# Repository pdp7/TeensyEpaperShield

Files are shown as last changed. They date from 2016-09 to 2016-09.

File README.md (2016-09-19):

# TeensyEpaperShield
Teensy shield designed by [Jarek Lupinski](https://hackaday.io/Jarek) to connect e-paper display from [Pervasive Displays](http://www.pervasivedisplays.com/products#iTC):
 > The Simplest Way To Start Playing With A Fascinating New Low-Power Screen!

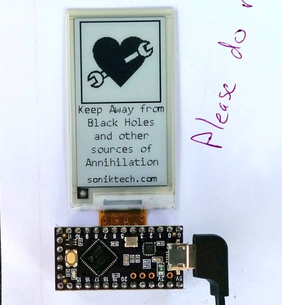
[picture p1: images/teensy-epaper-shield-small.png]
photo of assembled board (https://oshpark.com/shared_projects/3KynIVn6)


## OSH Park Shared Project
* [Teensy e-Paper shield](https://oshpark.com/shared_projects/3KynIVn6)

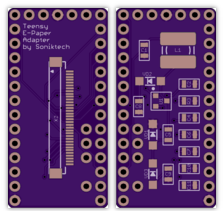
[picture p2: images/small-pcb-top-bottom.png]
PCB preview (https://oshpark.com/shared_projects/3KynIVn6)


## Blog posts
* [Teensy E-Paper shield](https://blog.oshpark.com/2016/08/27/teensy-e-paper-shield/)
* [Teensy E-Paper shield update](https://blog.oshpark.com/2016/09/07/teensy-e-paper-shield-update/)

## Hackaday.io project
* [Teensy E-Paper Adapter Board](https://hackaday.io/project/13327-teensy-e-paper-adapter-board)

## Design files
* [EpaperTeensyBoard.sch](https://cdn.hackaday.io/files/13327570182368/EpaperTeensyBoard.sch)
* [EpaperTeensyBoard.brd](https://cdn.hackaday.io/files/13327570182368/EpaperTeensyBoard.brd)

## Images
* [images dir](/images)

## Video
* [YouTube: Teensy E-Paper Shield](https://www.youtube.com/watch?v=xAe1GGP35UQ)

## Bill of Materials
* [Teensy 3.x](https://oshpark.com/teensy) or [Teensy LC](http://store.oshpark.com/products/teensy-lc)
* [Pervasive Displays 2.15" e-paper with ITC (E2215CS062)](http://www.digikey.com/product-detail/en/pervasive-displays/E2215CS062/E2215CS062-ND/5975949)
* [Hirose Electric Co Ltd FH34SRJ-34S-0.5SH FPC connector]( https://www.digikey.com/short/3hv1q0 )
* [Parts list exported from EAGLE](https://cdn.hackaday.io/files/13327570182368/EpaperTeensyBoardPartlist.txt)
* [Digi-Key shopping cart #1](http://www.digikey.com/short/3mhnrd)
* [Digi-Key shopping cart #2](http://www.digikey.com/short/3m9wq3)

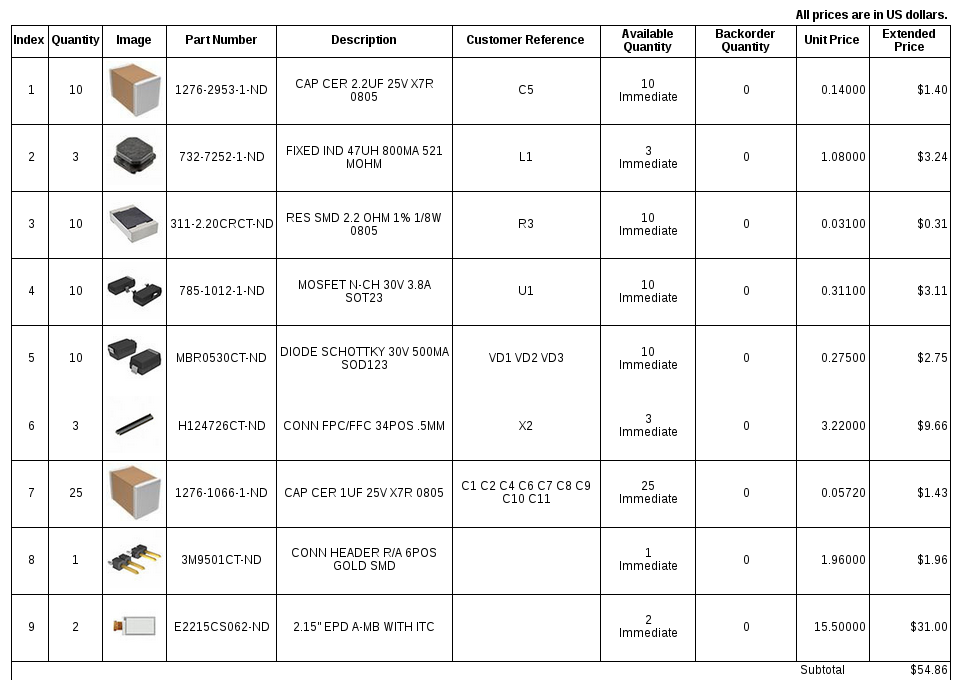
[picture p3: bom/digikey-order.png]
Digi-Key order


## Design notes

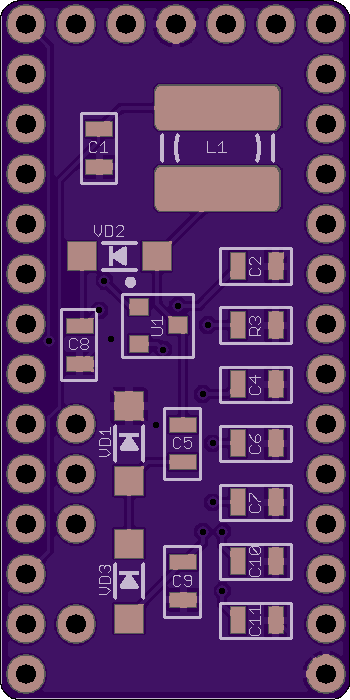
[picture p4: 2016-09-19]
images/pcb-big-bottom.png

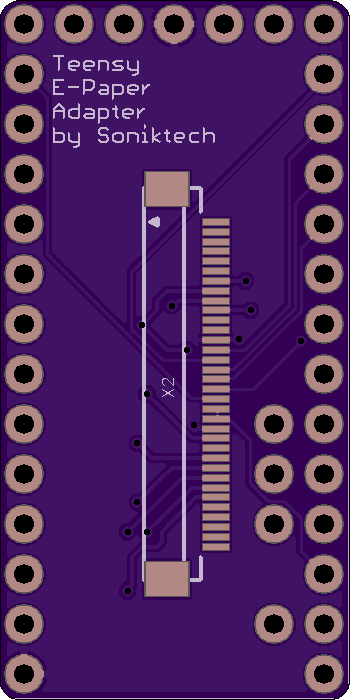
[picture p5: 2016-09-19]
images/pcb-big-top.png

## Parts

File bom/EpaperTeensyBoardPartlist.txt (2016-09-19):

Partlist

Exported from EpaperTeensyBoard.sch at 9/10/2016 6:15 PM

EAGLE Version 7.5.0 Copyright (c) 1988-2015 CadSoft

Assembly variant: 

Part     Value                 Device                 Package            Library                   Sheet

C1       1uF                   CAPACITOR_NP_0805      C0805              MF_Passives               1
C2       1uF                   CAPACITOR_NP_0805      C0805              MF_Passives               1
C4       1uF                   CAPACITOR_NP_0805      C0805              MF_Passives               1
C5       1uF                   CAPACITOR_NP_0805      C0805              MF_Passives               1
C6       1uF                   CAPACITOR_NP_0805      C0805              MF_Passives               1
C7       1uF                   CAPACITOR_NP_0805      C0805              MF_Passives               1
C8       1uF                   CAPACITOR_NP_0805      C0805              MF_Passives               1
C9       1uF                   CAPACITOR_NP_0805      C0805              MF_Passives               1
C10      1uF                   CAPACITOR_NP_0805      C0805              MF_Passives               1
C11      1uF                   CAPACITOR_NP_0805      C0805              MF_Passives               1
J1       TEENSY-3.1NOSILK      TEENSY-3.1NOSILK       TEENSY-3.1_NOSILK  SparkFun-Boards           1
L1       74404052470           L-USWE-TPC             POWER-CHOKE_WE-TPC rcl                       1
R3       2.2?/1%               RESISTOR_0805          R0805              MF_Passives               1
U1       AO3418                N-CHANNEL_FET_SOT-23-3 SOT-23-3           MF_Discrete_Semiconductor 1
VD1      MBR0530               DIODE-SCHOTTKY-SOD123  SOD123             diode                     1
VD2      MBR0530               DIODE-SCHOTTKY-SOD123  SOD123             diode                     1
VD3      MBR0530               DIODE-SCHOTTKY-SOD123  SOD123             diode                     1
X2       FH34SRJ-34S-0.5SH(99) FH12-34S-0.5SH         FH12-34S-0.5SH     con-hirose                1

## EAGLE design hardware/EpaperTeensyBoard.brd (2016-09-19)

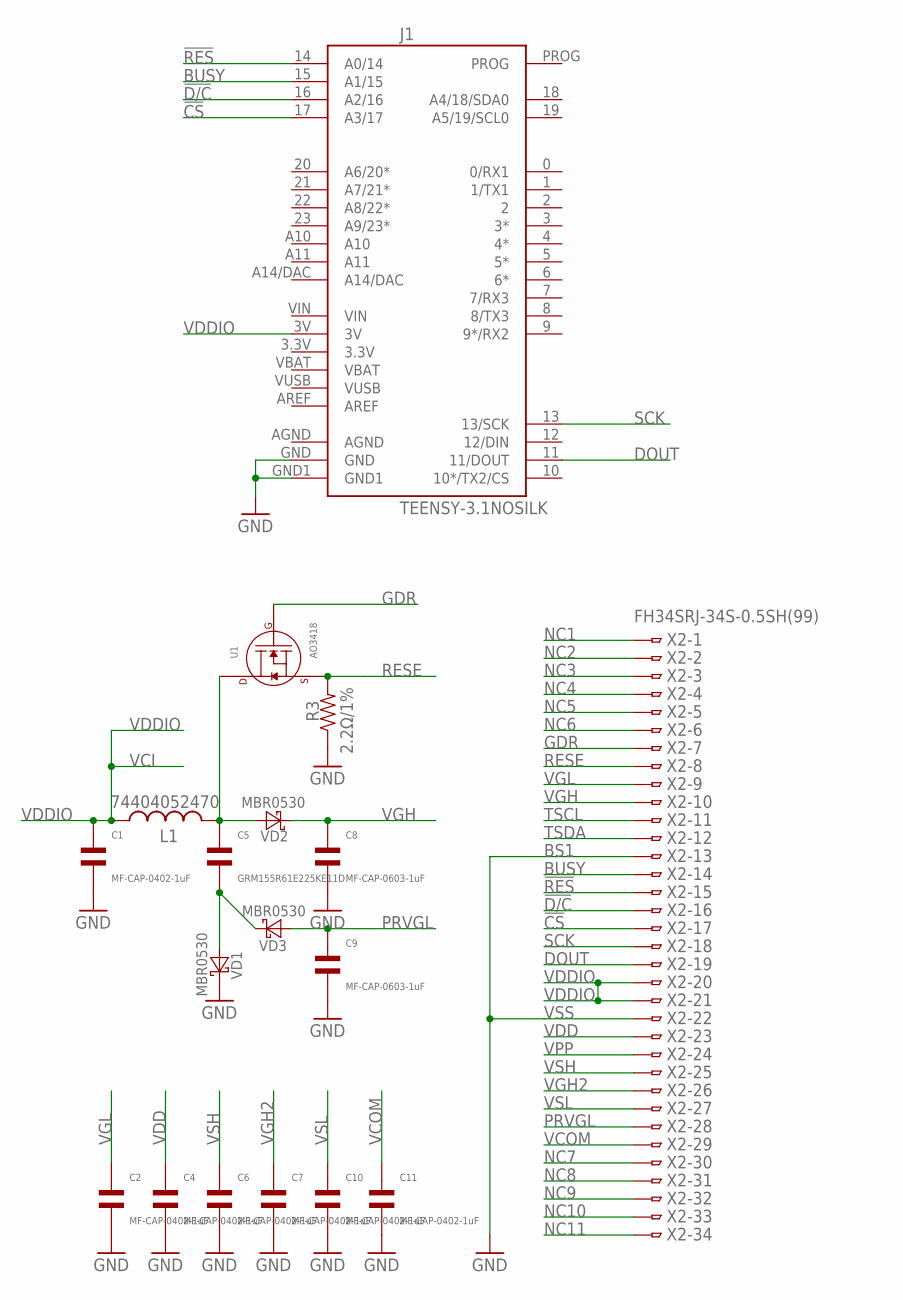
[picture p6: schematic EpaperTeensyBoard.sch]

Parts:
C1, C2, C4, C6, C7, C10, C11: MF-CAP-0402-1uF; C0805
C5: GRM155R61E225KE11D; C0805
C8, C9: MF-CAP-0603-1uF; C0805
J1: TEENSY-3.1NOSILK; TEENSY-3.1_NOSILK
L1: 74404052470; POWER-CHOKE_WE-TPC
R3: 2.2Ω/1%; R0805
U1: AO3418; SOT-23-3
VD1, VD2, VD3: MBR0530; SOD123
X2: FH34SRJ-34S-0.5SH(99); FH12-34S-0.5SH

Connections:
!CS: J1.17 (A3/17), X2.17
!D/C: J1.16 (A2/16), X2.16
!RES: J1.14 (A0/14), X2.15
BUSY: J1.15 (A1/15), X2.14
DOUT: J1.11 (11/DOUT), X2.19
GDR: U1.P$1 (GATE), X2.7
GND: C1.P$2, C2.P$2, C4.P$2, C6.P$2, C7.P$2, C8.P$2, C9.P$2, C10.P$2, C11.P$2, J1.GND, J1.GND1, R3.P$1, VD1.C, X2.13, X2.22
unnamed: C5.P$1, L1.2, U1.P$3 (DRAIN), VD2.A
unnamed: C5.P$2, VD1.A, VD3.C
NC1: X2.1
NC2: X2.2
NC3: X2.3
NC4: X2.4
NC5: X2.5
NC6: X2.6
NC7: X2.30
NC8: X2.31
NC9: X2.32
NC10: X2.33
NC11: X2.34
PRVGL: C9.P$1, VD3.A, X2.28
RESE: R3.P$2, U1.P$2 (SOURCE), X2.8
SCK: J1.13 (13/SCK), X2.18
TSCL: X2.11
TSDA: X2.12
VCOM: C11.P$1, X2.29
VDD: C4.P$1, X2.23
VDDIO: C1.P$1, J1.3V, L1.1, X2.20, X2.21
VGH: C8.P$1, VD2.C, X2.10
VGH2: C7.P$1, X2.26
VGL: C2.P$1, X2.9
VPP: X2.24
VSH: C6.P$1, X2.25
VSL: C10.P$1, X2.27

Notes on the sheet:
BS1
VSS
VCI

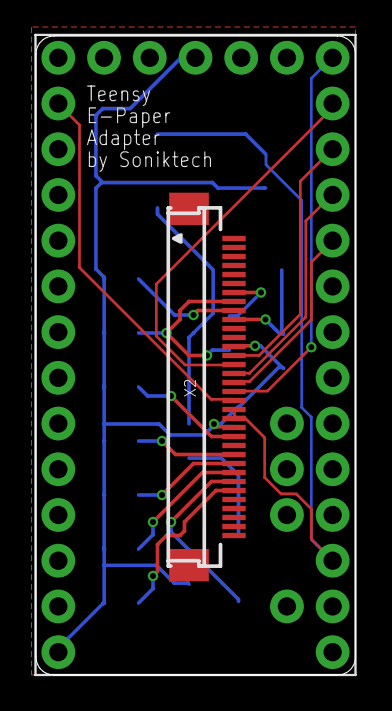
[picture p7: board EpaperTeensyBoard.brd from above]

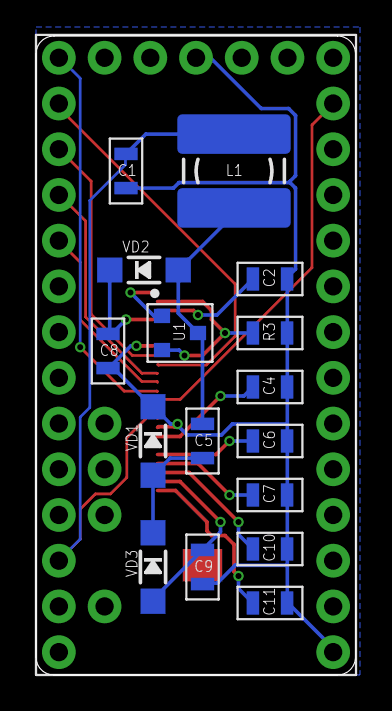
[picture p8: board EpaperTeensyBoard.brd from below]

Board: 2 copper layers, 17.8 x 35.5 mm, 18 parts (17 on the bottom side), 20 nets.

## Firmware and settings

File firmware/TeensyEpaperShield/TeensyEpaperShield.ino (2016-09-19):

// This program is based on demo code
// written by Jarek Lupinski on Hackaday.io:
// https://hackaday.io/project/13327/files

#include "epaper.h"

#define NMSG 9

// avoid the protect plastic tab until I take it off
#define VERT_OFFSET 36
#define VERT_MAX 150
#define LINE_HEIGHT 24
#define INIT_DELAY 2000
#define LOOP_DELAY 2000

Epaper epaper;

String banner[NMSG] = { "OSH Park  welcomes you to Portland Mini Maker Faire 2016" ,
                        "Teensy E-Paper Adapter Board by Jarek Lupinski: hackaday.io/Jarek",
                        "'The Simplest Way To Start Playing With A Fascinating New Low-Power Screen!' -Jarek",
                        "OSH Park: Perfect, Purple, Prompt PCBs. Made in the USA!",
                        "[oshpark.com] Upload EAGLE, KiCad or Gerbers",
                        " twitter: @oshpark       blog.oshpark.com       docs.oshpark.com  ",
                        "2 layer boards are $5 per square inch (with 3 copies of your board included in that price) and ship in under 12 calendar days from ordering",
                        "4 layer boards are $10 per square inch (also including 3 copies of your board), go to the fab once a week, and have a 2 week turn time from the fab.",
                        "2 Layer Medium Run Service: $1 per square inch, 150 square inch minimum. You can have as many different designs as you want, as long as each design is ordered in a multiple of 10 boards."
                      };


void setup() {
  epaper.initScreen();
  delay( INIT_DELAY );
}

void loop() {
  for ( int i = 0; i < NMSG; i++ ) {
    epaper.clearScreen();
    // display messages successivly lower on the display for visual "flare"
    int y = (i * LINE_HEIGHT) + VERT_OFFSET;
    epaper.placeStringAt(  (String)(banner[i]), 0, (y < VERT_MAX ? y : VERT_OFFSET ) );
    epaper.updateScreen();
    delay( LOOP_DELAY );
  }
}

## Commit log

2016-09-10 Add demo code from Jarek on Hackaday.io
    Demo for Teensy E-Paper Adapter Board by jarek319:
    https://hackaday.io/project/13327-teensy-e-paper-adapter-board
2016-09-19 Add EAGLE schematic and layout
    EAGLE design files by Jarek Lupinksi on Hackaday.io:
    https://hackaday.io/project/13327/files
    [EpaperTeensyBoard.brd, EpaperTeensyBoard.sch]
2016-09-19 add image of assembled board and osh park pcb preview
2016-09-19 add BoM info
2016-09-19 update BoM image

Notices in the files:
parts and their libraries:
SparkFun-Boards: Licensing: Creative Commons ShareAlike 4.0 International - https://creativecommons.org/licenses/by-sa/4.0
